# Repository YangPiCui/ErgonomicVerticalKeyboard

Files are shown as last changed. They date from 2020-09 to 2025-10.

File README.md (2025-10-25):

# Ergonomic Computer Keyboard (ECK)

## switching to FreeCAD and (extremely) slowly working on the next iteration
## let me know if you want to draw the case

## Introduction
Do you get a sore neck and stiff fingers from typing? Have you developed a stretched forth neck and a hump back?  
The keyboard and the mouse are the culprits. They force our hands to lay flat on the desk pronated, in turn stressing our neck.  
Now put your hands on the desk but rotate your palms to face each other. Do you start to feel your shoulders relaxed, your neck relieved, and your back straightened?    
The Ergonomic Computer Keyboard (ECK) allows you to feel exactly like that with the following features.
- The case orientates the key caps into a tilted formation, so that palms face each other more while typing. [[SafeType](https://safetype.com/index.php?id_product=1&controller=product) | [ergodox ez vertical stand](https://www.thingiverse.com/thing:2748084)&nbsp;| [Ergodox EZ tent kit](https://www.thingiverse.com/thing:1433117) | [A Similiar Project](https://thomasbaart.nl/2019/01/20/vertikeeb-making-a-vertical-keyboard-part-1/)]
- Concave design accomodate fingers' natural paths. [[Kinesis Advantage 2](https://kinesis-ergo.com/shop/advantage2/)  | [British patent 1,016,993](https://geekhack.org/index.php?topic=63415)]  
- An efficient, customizable keymap layout to distribute load on each finger evenly according to their relative strengths.  
- Little fingers' extra columns have been reassigned to other fingers to alleviate sore pinkies.  
- Make the keyboard as compact as possible to save desk space for extra accessories such as the mouse.  

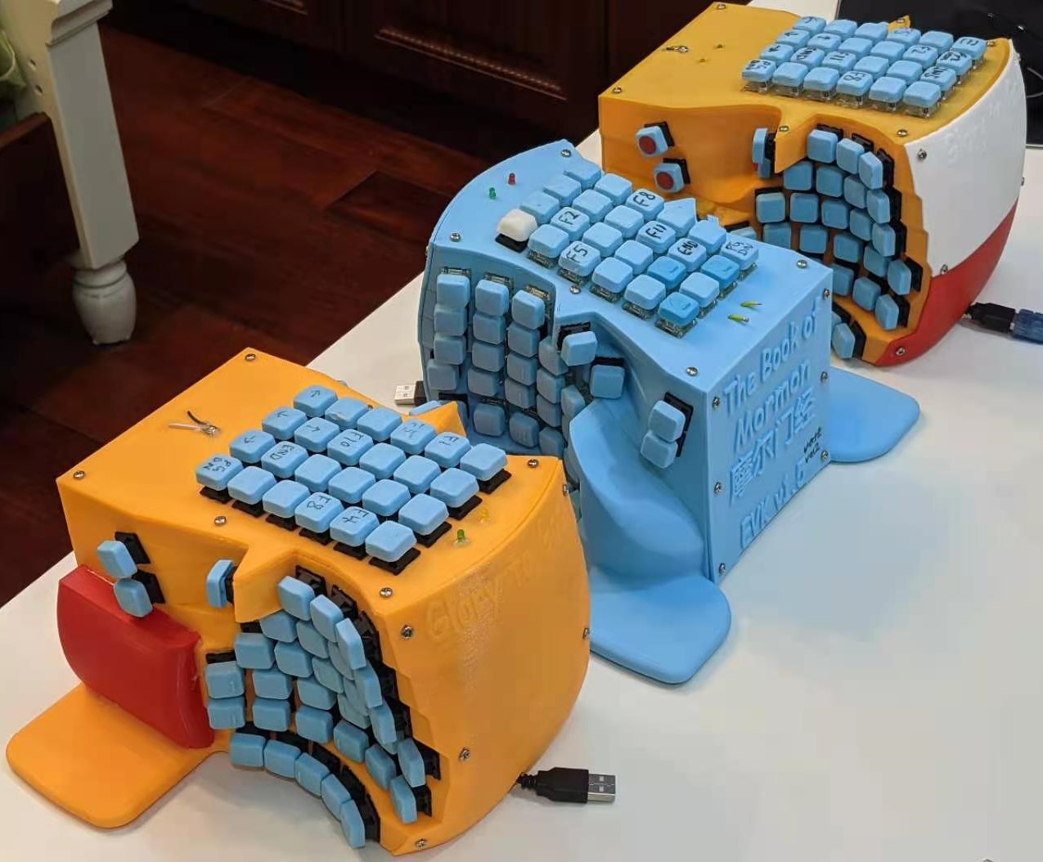
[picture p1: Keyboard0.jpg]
  
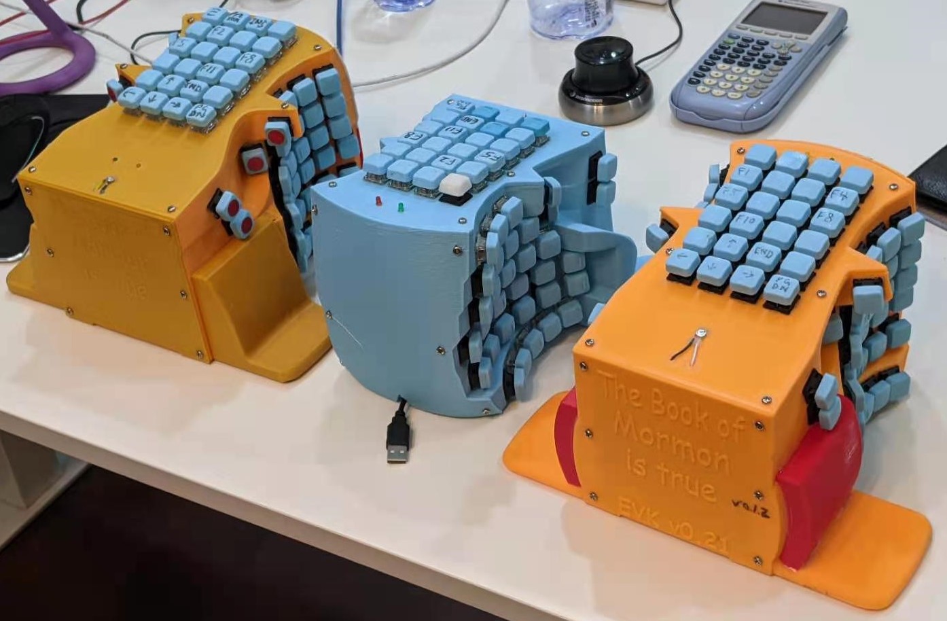
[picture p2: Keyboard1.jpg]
  

## [Versions <- click](Versions)  
I have included all necessary build instructions for each ECK version in the Versions folder.  
It takes one about one work week to build an ECK from start to finish with all the parts.

## [Keymap Optimization](KeymapOptimization) (Under Development)

## External Resources
[Main Reddit Thread](https://www.reddit.com/r/ErgoMechKeyboards/comments/g28c2i/ergonomicverticalkeyboard_thread/) | [Old](https://www.reddit.com/r/ErgoMechKeyboards/comments/fvxuw1/need_help_combining_all_of_the_good_features_from/) | [Older](https://www.reddit.com/r/MechanicalKeyboards/comments/fumlvb/possible_to_absorb_and_combine_all_of_the_good/)  

[reddit.com/r/MechanicalKeyboards/](http://reddit.com/r/MechanicalKeyboards/)&nbsp;|&nbsp;[https://www.reddit.com/r/ErgoMechKeyboards/](https://www.reddit.com/r/ErgoMechKeyboards/)  
[https://geekhack.org/](https://geekhack.org/)  
[Xah Keyboard Guide](http://Xah%20Keyboard%20Guide)  
[Reddit Post 0](https://www.reddit.com/r/MechanicalKeyboards/comments/fumlvb/possible_to_absorb_and_combine_all_of_the_good/) | [Reddit Post 1](https://www.reddit.com/r/ErgoMechKeyboards/comments/fvxuw1/need_help_combining_all_of_the_good_features_from/) | [Main Reddit Thread ](https://www.reddit.com/r/ErgoMechKeyboards/comments/g28c2i/ergonomicverticalkeyboard_thread/)  

[Ergodox](https://www.ergodox.io/)  
[Dactyl Keyboard Wiring](https://github.com/adereth/dactyl-keyboard/blob/master/guide/README.org#wiring)   
[Ergo-Dox keyboard assembly](https://www.youtube.com/watch?v=x1irVrAl3Ts)  
[Keyboard PCB Guide](https://github.com/ruiqimao/keyboard-pcb-guide)   
[GMK Carbon Original Ergodox build log](https://imgur.com/a/3riAB)  
[Dactyl Manuform Mini DIY Ergonomic Mechanical Keyboard Build Log](https://www.beekeeb.com/dactyl-manuform-mini-mechanical-keyboard-build-log/)   
[Detailed guide to making a custom keyboard](https://www.reddit.com/r/MechanicalKeyboards/comments/4l0p41/guide_detailed_guide_to_making_a_custom_keyboard/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)  
[Building your own keyboard (from scratch)](https://medium.com/@monkeytypewritr/building-your-own-keyboard-from-scratch-bd0638c40850)  

[Windows 10 Key Mapping software](https://thegeekpage.com/top-10-best-free-key-mapping-software-for-windows-10/)&nbsp;| [SharpKeys](https://github.com/randyrants/sharpkeys/releases)

## [How to Donate](https://github.com/YangPiCui/ProjectIdeas/blob/main/README.md#how-to-donate-in-descending-preference-for-me)

###### [ODC Open Database License v1.0](https://choosealicense.com/appendix/)  (free but no patent or commercial use)

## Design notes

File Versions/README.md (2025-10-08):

# Versions  
To dos:  
Rebase Github Pull Request for the firmware

## [ECK_v0.2.0](ECK_v0.2.0) (FreeCAD)
People can't blind type.
Tilt keywell instead of making it vertical.
Rename ErgonomicVerticalKeyboard to ErgonomicComputerKeyboard

## [EVK_v0.1.2](EVK_v0.1.2) (Siemens NX license expired)
I redesigned the Handrest to let hands move more freely.
* Keys
  * Chamfer the keycap stems so they don't get caught on the switches  
  * Tighten switch mount tolerance so the keys don't wiggle side to side
  * Thin the keycap walls slightly
  * Move homekey's emboss forward by 1mm.
  * keycapBaseModel stemClearance 0.02->0.03->0.04
* Key Positioning
  * finger home row resting angle p411 47->48
  * base keywell radius 87 -> 80 -> 60 ->50
  * Row separation mid 21->19->19.2; pinky 17 -> 15.3; 
  * topPlate keySpacingX keySpacingY 19.5->19->19.5->19.2
  * dZIndexToMid 19.5 -> 19 -> 19.5
  * angleIndexToMidXY 3 -> 0 -> 2 -> 3
  * knuckleRadiusXZPlane 400 -> 100 -> 170 -> 200
  * knuckleRadiusYZPlane 420 -> 500
  * Switch mount wall and other walls' thickness 1.8 -> 1.5 -> 1.65
  * Fix thin walls
  * ASM_ThumbKeys DCS1 x:40->42
  * Spacekey distance to center of rotation 50->48
  * Enter key offset -x 2->3; y 1; z 20
  * Increase LED clearance hole diameter.
  * handSeparation 220->230
  * thicknessTopPlate 2.7 -> 2.5mm
* Handrest
  * Redesign handrest to be a separate glue-on.
  * Palm Rest x 40->30->23->29->28->26->27->29, y -65 -> -40, z -20 -> -10;  angle 8->9;  
  * Bottom Rest Z -52 -> -51 -> -49 -> -50 -> -45 -> -52 -> -50 -> -49; side extension 10 -> 15; front offset 6->13->10->8
* Miscellaneous
  * Enlarge LED clearance holes
  * thicknessText .6mm

## [EVK_v0.1.1](EVK_v0.1.1)
I removed the row steps to let fingers move more freely.
* Use normal keycaps for thumbkeys
* Reduce keycap height
* Reduce keycap support area. Keycaps can now be printed without supports.
* Clean up sketch in ASM_MASTER_MidFingeColumn.prt which brings keys slightly closer to the fingers
* Use 0.4mm nozzle and 0.3mm layer height. Adjusted tolerances accordingly.
* Lower switch mount height from 2.4 to 1.8mm
* Redesign key well to replace step-like rows with a semi circle instead. This resembles Kinesis Advantage. Keycaps no longer block finger movement.
* Scale index and ring finger row separation to that of the middle finger. Apply minimum row separation for the little finger row.
* Decrease colume angles
* Flatten colume to colume curvature slightly
* Thin side walls
* Thicken top plate
* Adjust Thumbgrip to better fit the palm
* Move enter key closer to space key
* Thicken screw mounting holes  
* Front plate thicken, not extrude  
* Adjust the angle and height of the hand rests  
* Enlarge the back of the hand rests  
* Print with a better 3D printer  

## [EVK_v0.1.0](EVK_v0.1.0)
I deployed a 90 key one-piece design. This simplifies the electronics, and uses all of Teensy 2.0's pins.   
* Deploy full-sized keycaps  
* Increase row separation
* Flatten keywell slightly
* Add QWERTY keymap   
Update Versioning  
  Keyboard Layout Editor   
  Github links  
  QMK Github  

## [EVK_v0.0](EVK_v0.0) 
This is the first working prototype. It uses a split design. The firmware is based on the Dactyl Keyboard running on Teensy 2.0.

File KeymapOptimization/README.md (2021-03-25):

# Algorithmically Optimized Keymap
The layout should accommodate world's languages according to their usage.
## 0. Preparation
[The Carpalx Layout - simulated annealing](http://mkweb.bcgsc.ca/carpalx/?simulated_annealing) | [white_keyboard_layout](https://github.com/mw8/white_keyboard_layout) | [ThinQu Layout](https://microexploitation.com/2018/06/04/thinqu/)  
Download sample word data. [World's Language Usage](https://www.vistawide.com/languages/top_30_languages.htm)  
[English Letter Frequencies](https://norvig.com/mayzner.html)  
[Chinese Letter Frequencies](http://xahlee.info/kbd/chinese_pinyin_letter_frequency.html)  
Weight the frequencies with the ratio of total number of speakers of each language.  
[Top 30 languages of the world](https://www.vistawide.com/languages/top_30_languages.htm)  
Get symbol frequencies for 'spaces', 'enter', 'comma'... from literature and from codes in (C++, Python, etc.).   
[http://xahlee.info/comp/computer_language_char_distribution.html](http://xahlee.info/comp/computer_language_char_distribution.html)  

## 1. Scoring Logic
Each finger's usage should be proportional to its strength, the cube of its diameter.   
Diameter of my left index finder (LI): 56mm / LM: 54mm / LR: 53mm / LP: 47mm  
So the ratio of finger key presses should be 1.69 : 1.52 : 1.43 : 1.  
how comfortably one presses simple operations such as 'ctrl + c' needs to be taken into account.  
If a hand changes row, the other hand types two charactors.    
Change two rows with two different finger better than change two rows with the same finger.  
switch 1 or 2 rows needs the other hand to type two letters to be optimal. Switching 3 rows requires the other hand to strike 3 times.  
make the right index and mid fingers type slightly less, as most people use these two fingers to click the mouse.  

## 2. Implementation
Next step:  
1. ~~Break down the problem into smaller parts for C++.~~
2. Figure out how to do simulated annealling.

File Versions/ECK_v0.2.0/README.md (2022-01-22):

  
  
 
   
  
Please refer to EVK_v0.1.2 for build instructions.   
  
Print sideStandingMount.3mf and flatLayingMount.3mf to check switch fit and tolerance.  
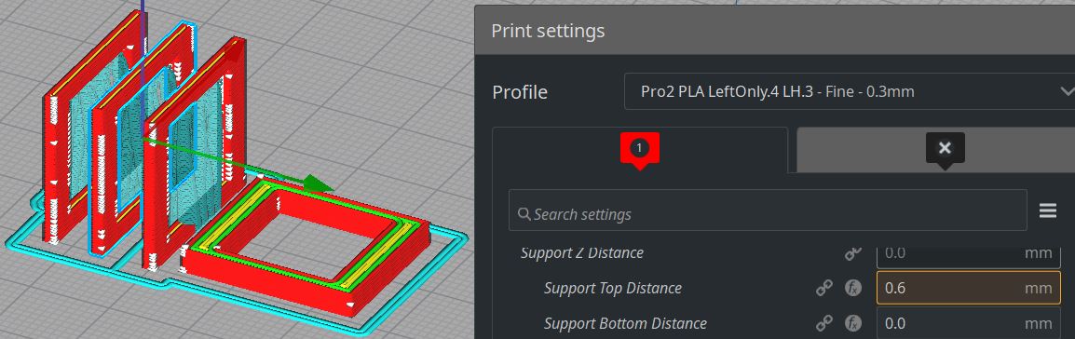
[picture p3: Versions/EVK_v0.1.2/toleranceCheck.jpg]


###### [ODC Open Database License v1.0](https://choosealicense.com/appendix/)  (free but no patent or commercial use)

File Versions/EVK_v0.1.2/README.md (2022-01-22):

  
  
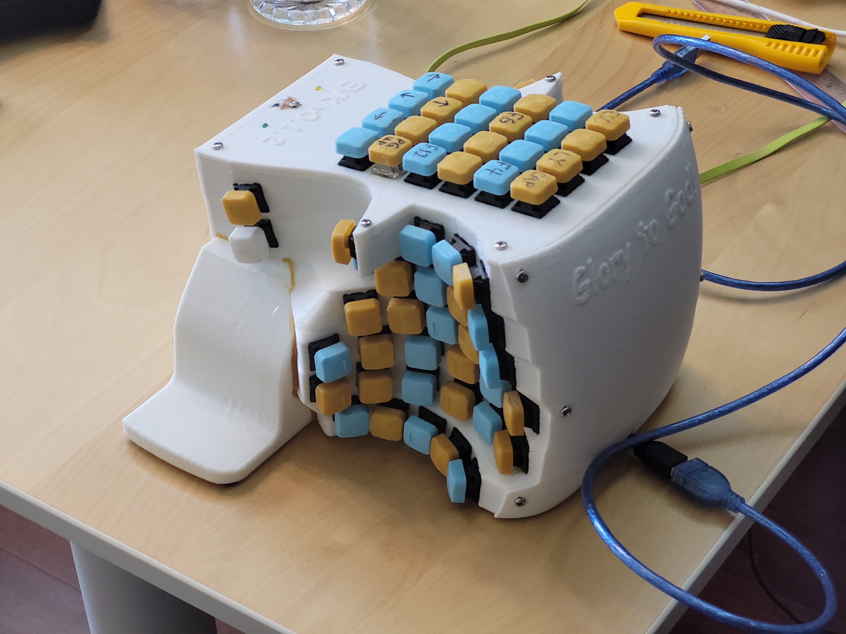
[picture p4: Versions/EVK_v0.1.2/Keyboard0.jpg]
 
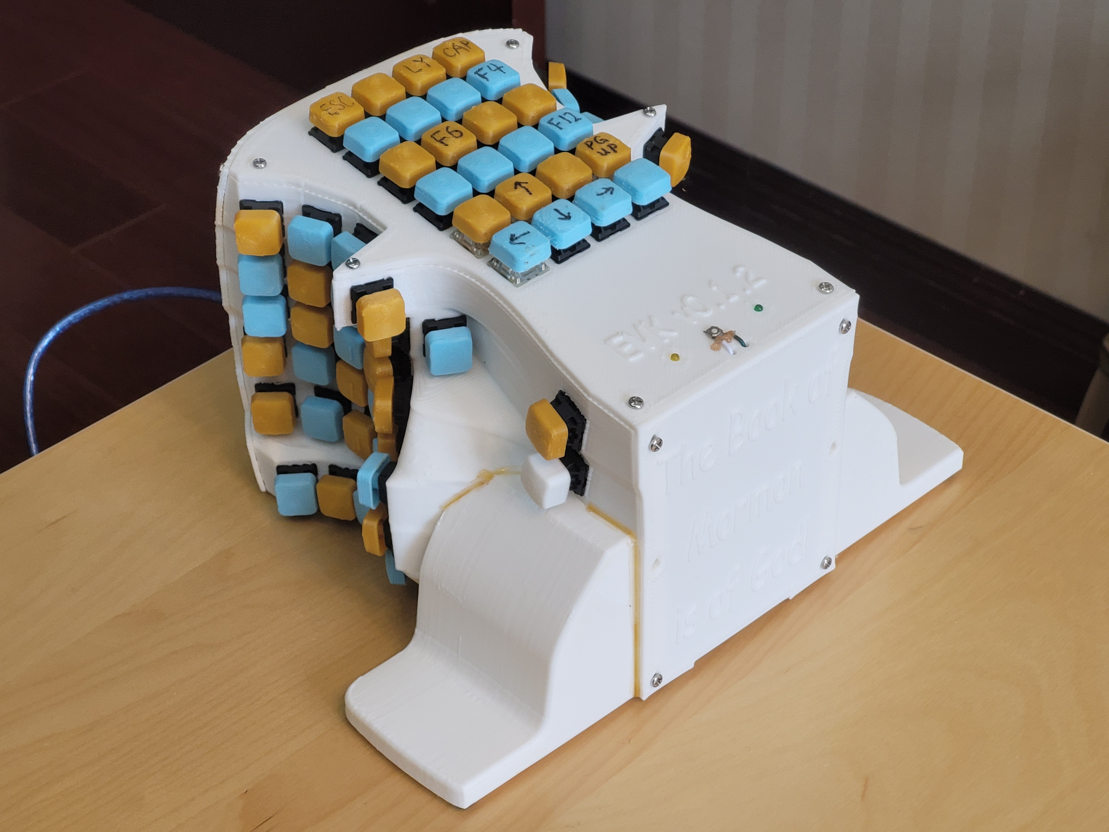
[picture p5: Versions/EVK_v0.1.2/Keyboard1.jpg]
   
  
Please refer to EVK_v0.1.1 for build instructions.   
  
Print sideStandingMount.3mf and flatLayingMount.3mf to check switch fit and tolerance.  


###### [ODC Open Database License v1.0](https://choosealicense.com/appendix/)  (free but no patent or commercial use)

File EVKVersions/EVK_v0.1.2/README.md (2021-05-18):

  
  
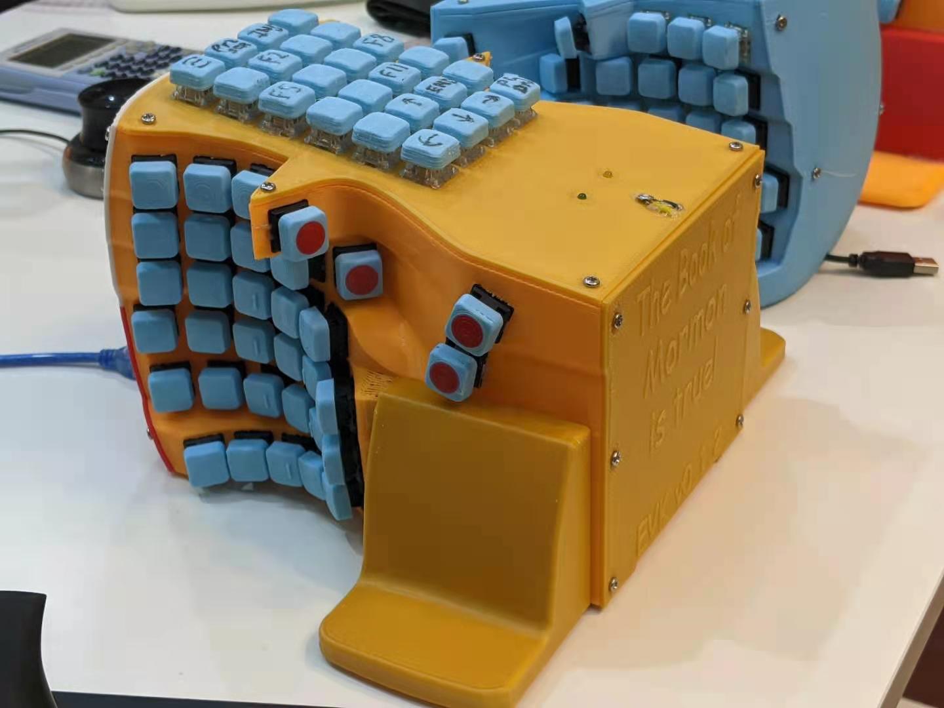
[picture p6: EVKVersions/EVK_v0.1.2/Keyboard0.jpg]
 
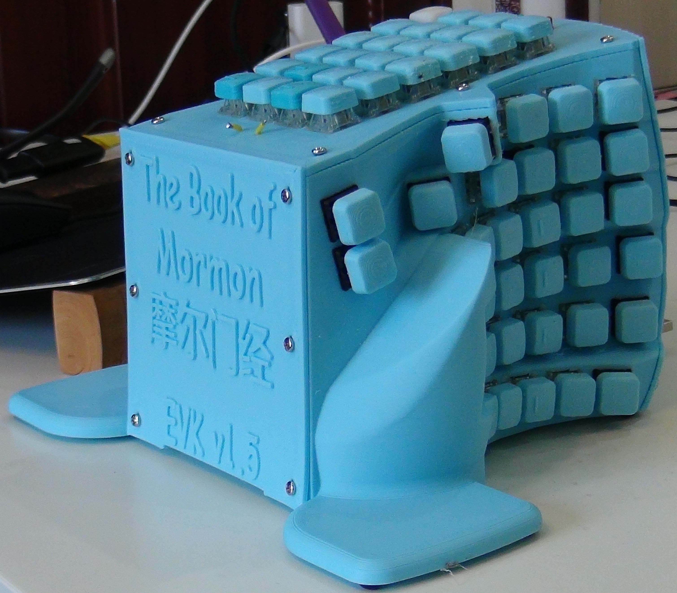
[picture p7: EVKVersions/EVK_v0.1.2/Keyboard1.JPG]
   
  
Please refer to EVK_v0.1.1  
  
Test print SwitchMountLeftRight.3mf and SwitchMountTop.3mf to check switch fit.  


###### [ODC Open Database License v1.0](https://choosealicense.com/appendix/)  (free but no patent or commercial use)

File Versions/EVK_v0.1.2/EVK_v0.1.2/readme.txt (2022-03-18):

+ ToleranceAndClearance.prt: determine the nozzle size, layer height and Support Top Distance.
+ Adjust SwitchMount.prt and test print SwitchMount3DPrintTest.prt for clearance 
    - Adjust print support top distance in Cura (2*layer height for easy support removal)
    - Adjust supportZClearance in ToleranceAndClearance.prt 
	- Adjust switch thickness. This is the side plate's wall thickness
	- Lay mount flat and remove the extra Z clearance to test the mount slots' fit on the top plate
+ ASM_Key.prt: modify the shape of keys
+ Modify master midfinger and its family parts for row separation and key orientation.
+ Case.prt
    - Adjust the curvatures in BaseKnucklePath
	- Adjust angleIndexToMidXY expression
	- Adjust dZIndexToMid expression
	- Adjust ThumbKeys positioning

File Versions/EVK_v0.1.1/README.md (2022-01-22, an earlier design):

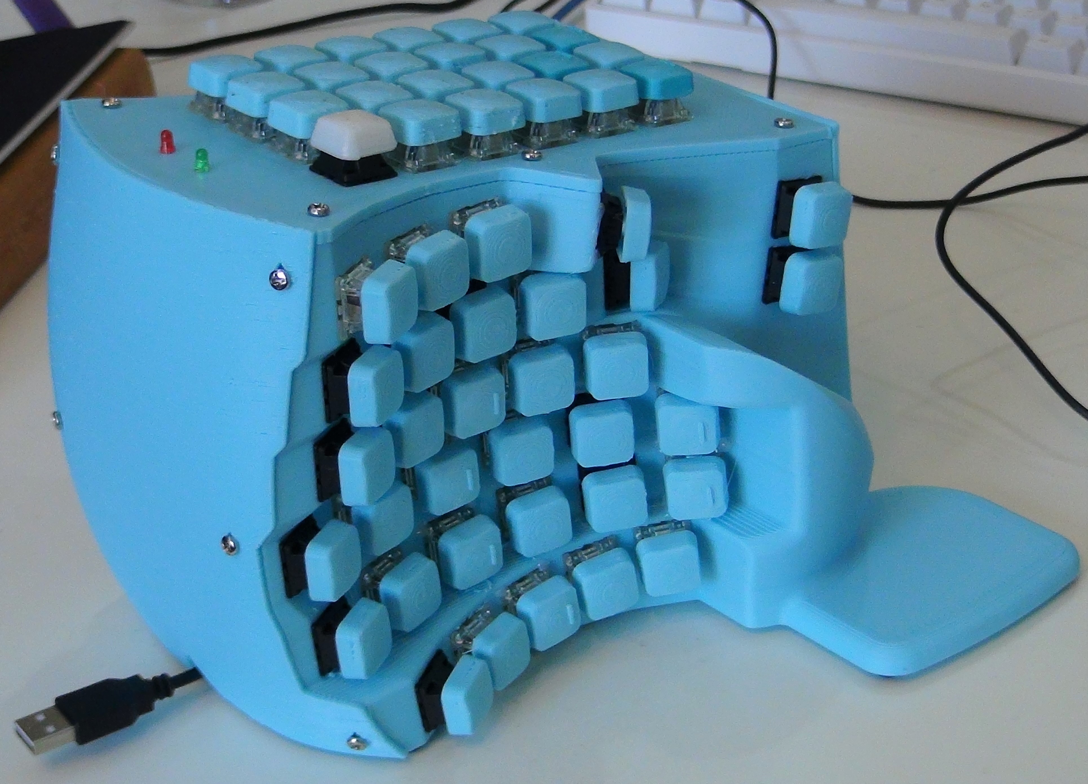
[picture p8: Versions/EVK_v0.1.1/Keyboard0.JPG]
  
  
  
Please refer to EVK_v0.1.0 for build instructions.    

### Left Right and Front  
* Nozzle Diameter 0.4mm  
* Layer Height 0.3mm  
* Line Width 0.7mm  
* Support Line Width 0.32mm  
* Tree Support Top Distance 0.6mm, or twice the layer height. IMPORTANT. Do NOT set this value greater than what I have specified, otherwise the keyswitch might not fit.  
  
### Keycaps  
* Nozzle Diameter 0.3mm  
* Layer Height = 0.15mm  

###### [ODC Open Database License v1.0](https://choosealicense.com/appendix/)  (free but no patent or commercial use)

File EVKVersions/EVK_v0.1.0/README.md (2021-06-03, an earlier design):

# 0. Part List  
* 1x Teensy 2.0 USB Board. （开发板）  
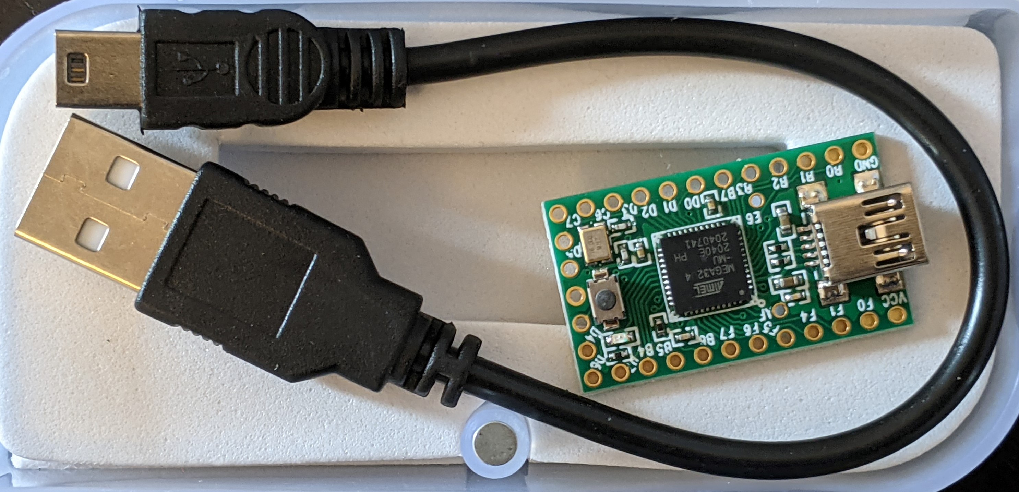
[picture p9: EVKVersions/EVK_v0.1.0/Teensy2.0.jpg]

* 90 Cherry Mechanical Switch. （樱桃轴）
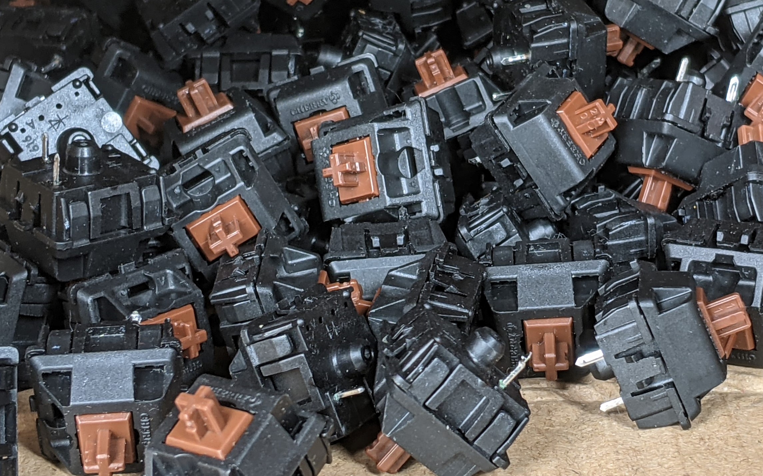
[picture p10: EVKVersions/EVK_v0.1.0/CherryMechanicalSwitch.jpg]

* 90 1N4148 diode.（开关二极管）One diode for each key switch.
* 2x 3mm T1 LEDs. （发光二极管）  
* 2x 1kΩ resistors to connect in series with the LEDs.（电阻）
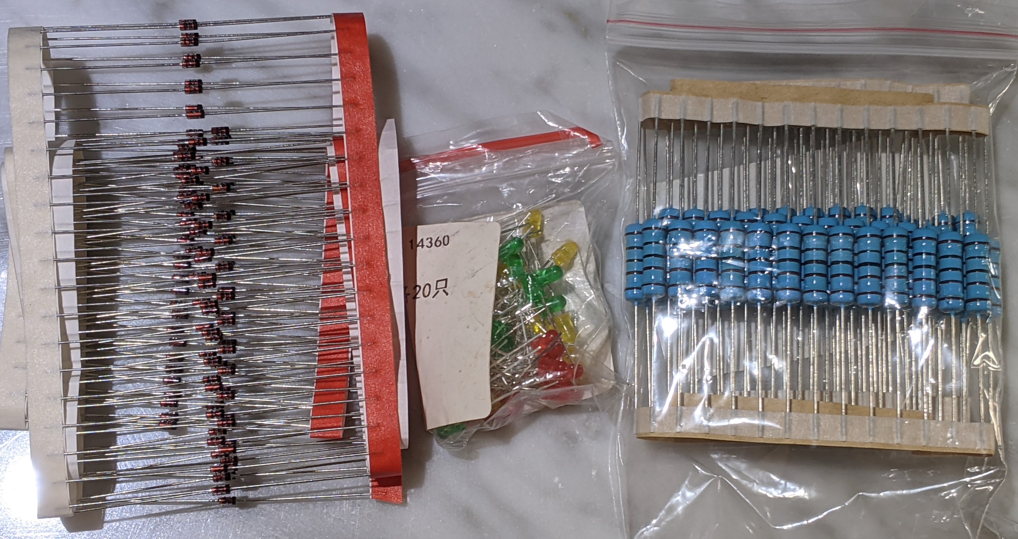
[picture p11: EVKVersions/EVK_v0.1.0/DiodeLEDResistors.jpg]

* 0.6mm (wire diameter) tin-coated naked wire.
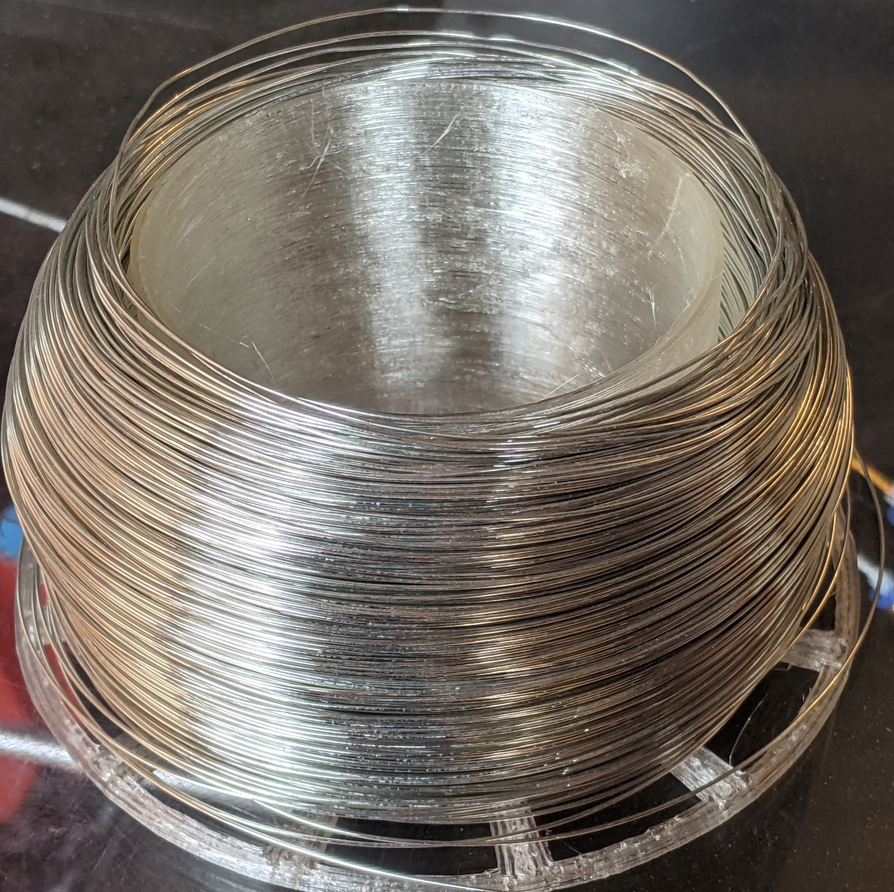
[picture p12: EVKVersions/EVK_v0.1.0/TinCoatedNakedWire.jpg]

* 20cm long, 0.6mm (core diameter) sillicon wrapped wire. Get these pre-soldered ones to save time.
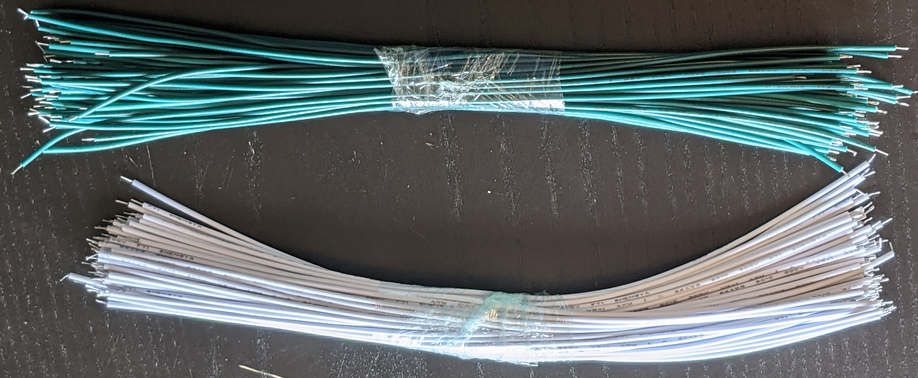
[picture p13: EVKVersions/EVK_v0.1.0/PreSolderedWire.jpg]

* 24 M3x6mm flat tip self-tap screws.
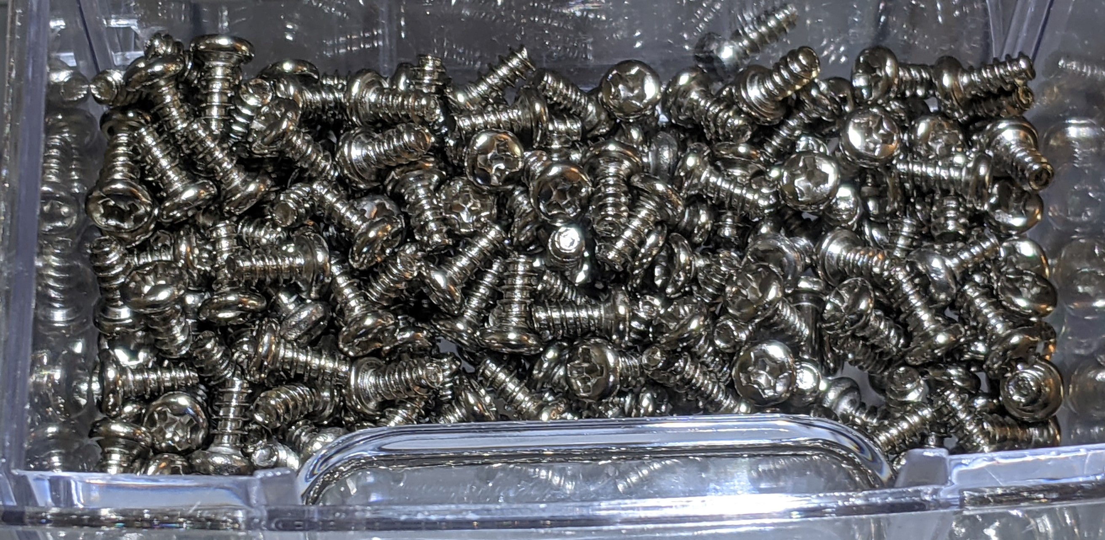
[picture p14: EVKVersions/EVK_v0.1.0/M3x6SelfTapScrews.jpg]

* 10 8mm diameter x 3mm tall silicon dome sticker feet.
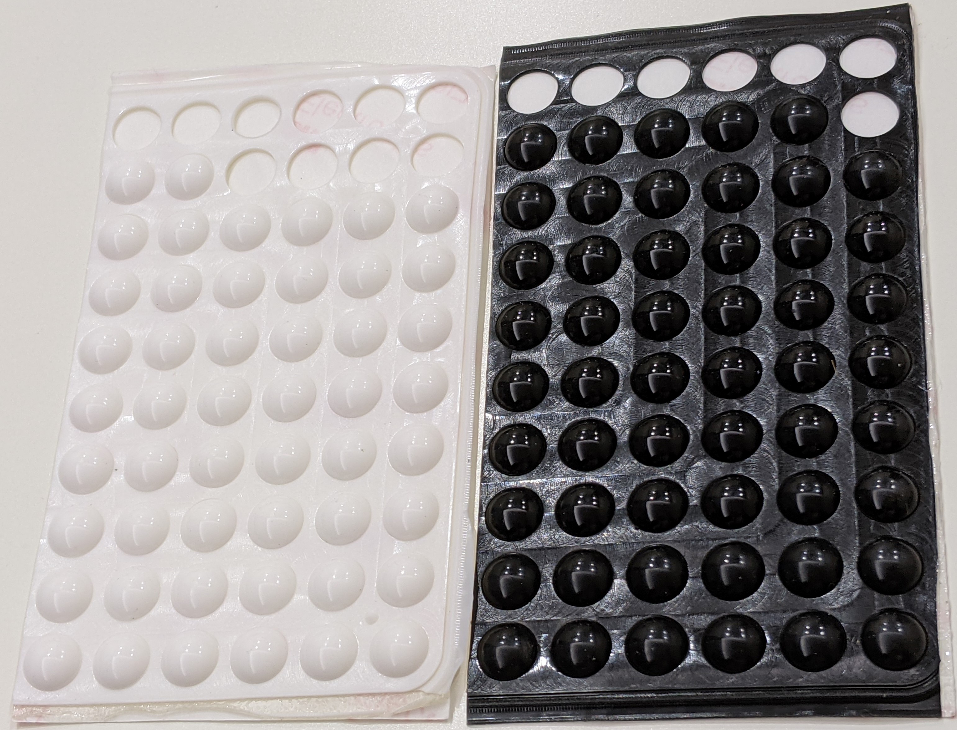
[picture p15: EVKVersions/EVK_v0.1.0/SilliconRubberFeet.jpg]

* Soldering Iron and Hot Glue Gun.

# [1. Case Design](CaseDesign) 
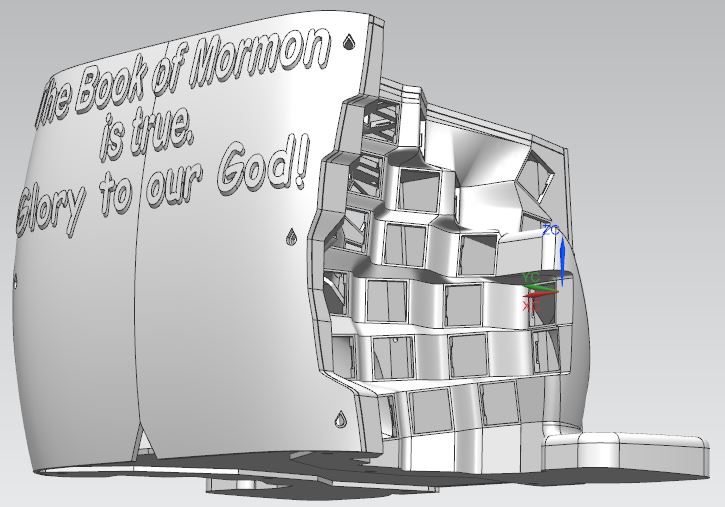
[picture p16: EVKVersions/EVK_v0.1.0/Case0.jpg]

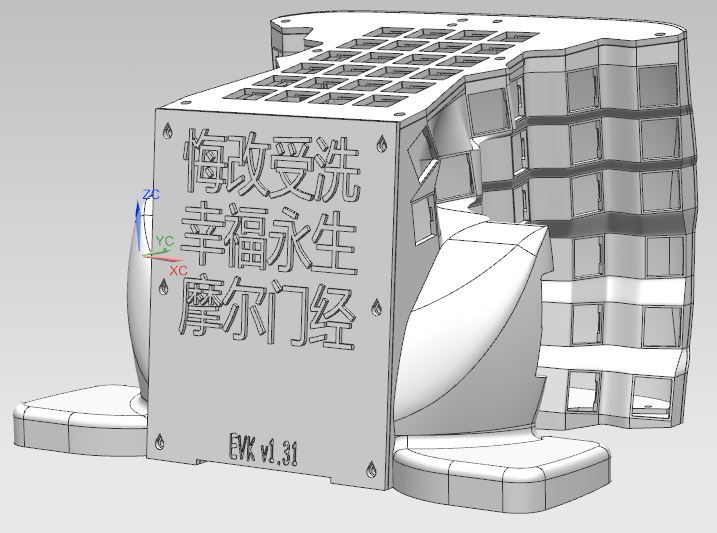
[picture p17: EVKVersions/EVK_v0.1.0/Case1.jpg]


# 2. Keymap 
[Layer0](http://www.keyboard-layout-editor.com/#/gists/2fc38dca845ec5f253bac7c052df82da)  
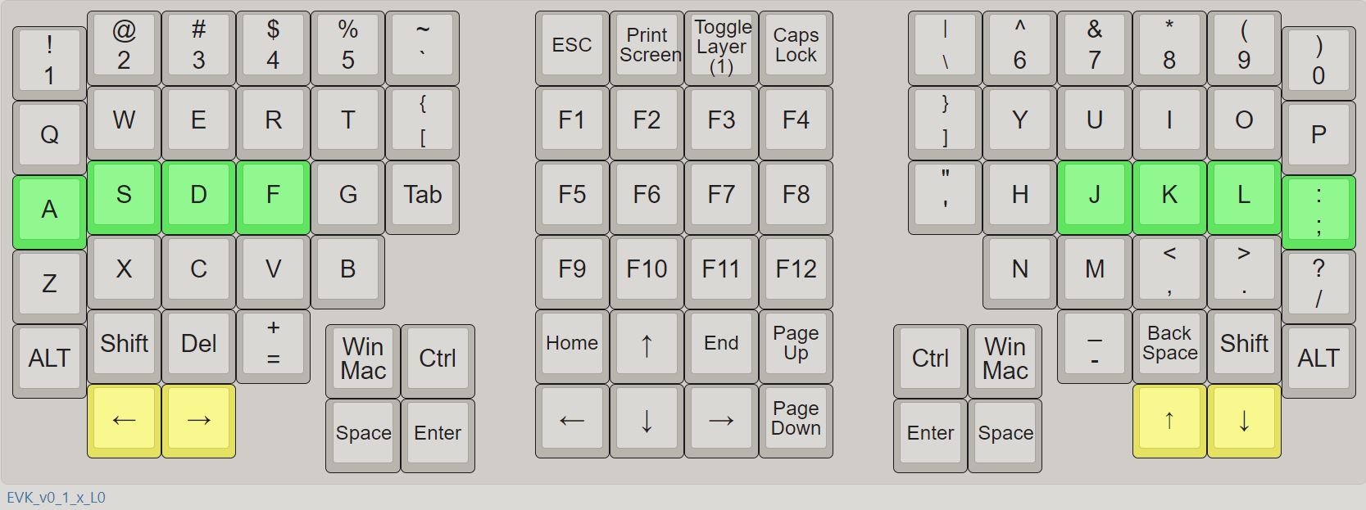
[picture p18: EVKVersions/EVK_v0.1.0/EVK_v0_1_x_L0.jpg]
  
[Layer1](http://www.keyboard-layout-editor.com/#/gists/1d35c2bdc8fc2de6860daa4e2ee97f45)  
I manually designed a keymap based on English [letter](https://norvig.com/mayzner.html) and [character](http://xahlee.info/comp/computer_language_char_distribution.html) frequencies. [It fares well against other traidtional layouts according to the Keyboard Layout Analyzer.](http://patorjk.com/keyboard-layout-analyzer/#/load/hqrGn4NG)  
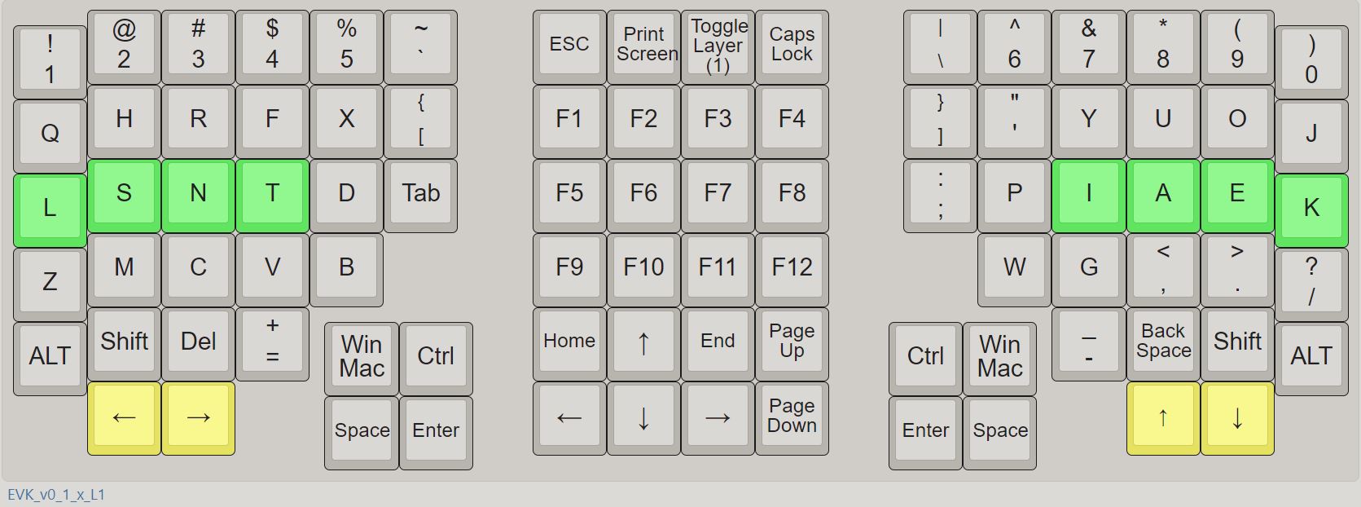
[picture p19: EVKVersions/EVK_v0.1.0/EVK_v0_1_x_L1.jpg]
  

# [3. Electronics, Firmware and Software](ElectronicsFirmwareAndSoftware)

# 4. 3D Print 
"./3DPrintFiles/"  
"./CuraSlicerSettings/" 
The parts are of high precision. The fits are transitional clearance. [Calibrate](https://github.com/YangPiCui/3DPrinterCalibrationAndTuning/) your 3D printer accurately and follow the instructions closely. 

### Left Right and Front  
* Nozzle Diameter 0.3mm
* Layer Height 0.24mm
* Line Width 0.54mm
* Support Line Width 0.24mm for easy support removal   
* Tree Support Top Distance is 0.48mm, or twice the layer height. IMPORTANT. Do NOT set this value greater than what I have specified, otherwise the keyswitch might not fit. 
Print the Left Right and Front as if they would normally stand on the build plate. Set brim distance to 0mm for Front but not for Left or Right.  
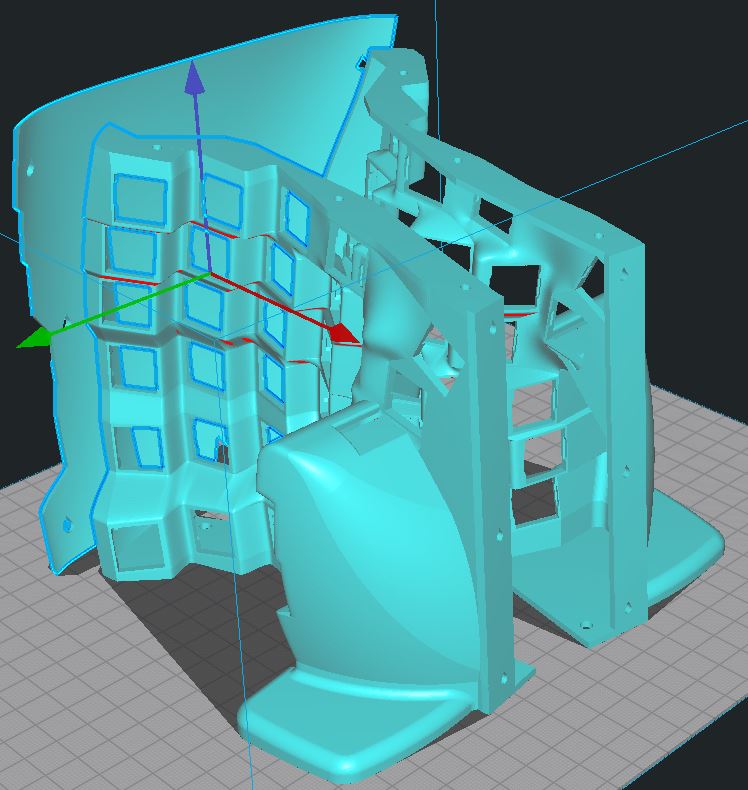
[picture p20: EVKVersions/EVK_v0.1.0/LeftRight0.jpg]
  
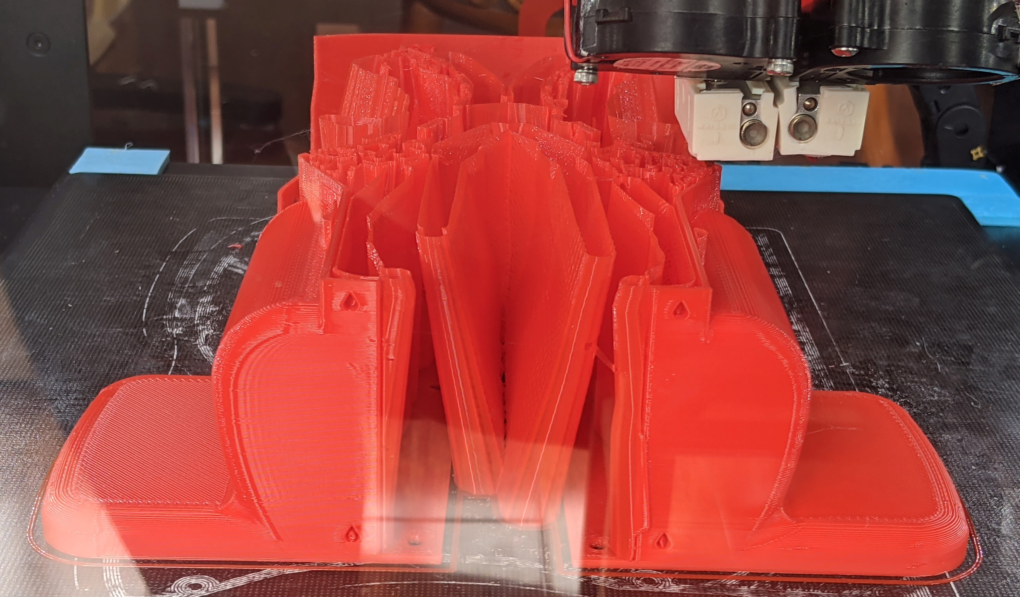
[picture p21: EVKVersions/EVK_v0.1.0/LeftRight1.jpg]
  
  
### Top Bottom and Back
If switches do not fit on the Top Plate. Try adjusting the Horizontal Expansion in Cura. 
  
### Keycaps
The keycaps are a press-fit onto the Cherry Switches!  
* Nozzle Diameter 0.3mm
* Layer Height = 0.16mm 
* Support still needed in this version. No support necessary starting at v0.1.1. 
* Brim & Support Brim = off; They are painful to remove.  
Print the keycaps as if they would sit on the build plate.  
KeycapHome x 12 (8 for the home row and 4 for the most bottom row)   
KeycapThumb x 4   
KeycapNormal x 74   
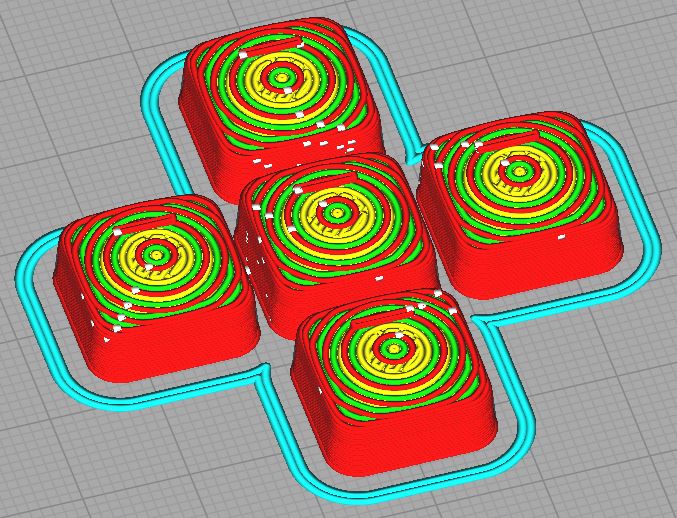
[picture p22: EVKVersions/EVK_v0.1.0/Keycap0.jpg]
    
Use a knife to trim the excess edges of the printed keycaps.

## 5. Assembly

### Hot-glue Cherry Key Switches
Put some hot glue on the four corners of each keyswitch to secure it on the plates. Do it on the inside for a nicer outer finish.
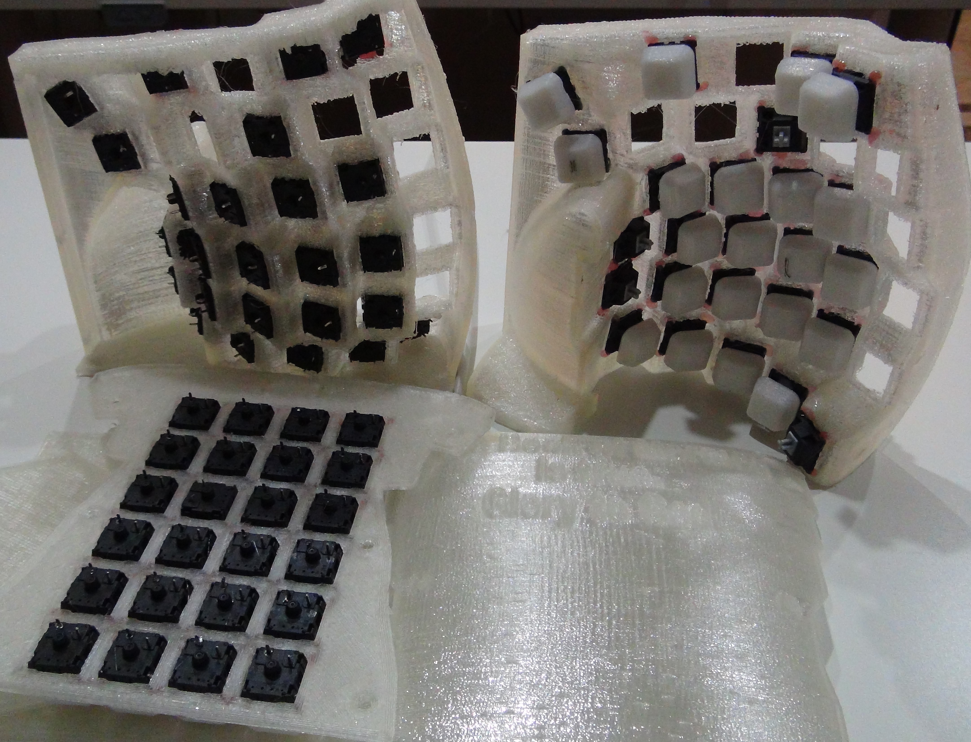
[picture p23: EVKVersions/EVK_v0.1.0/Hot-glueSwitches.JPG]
  

### Wire up the Keyboard Matrix  
Rows and columns on the physical keyboard:  
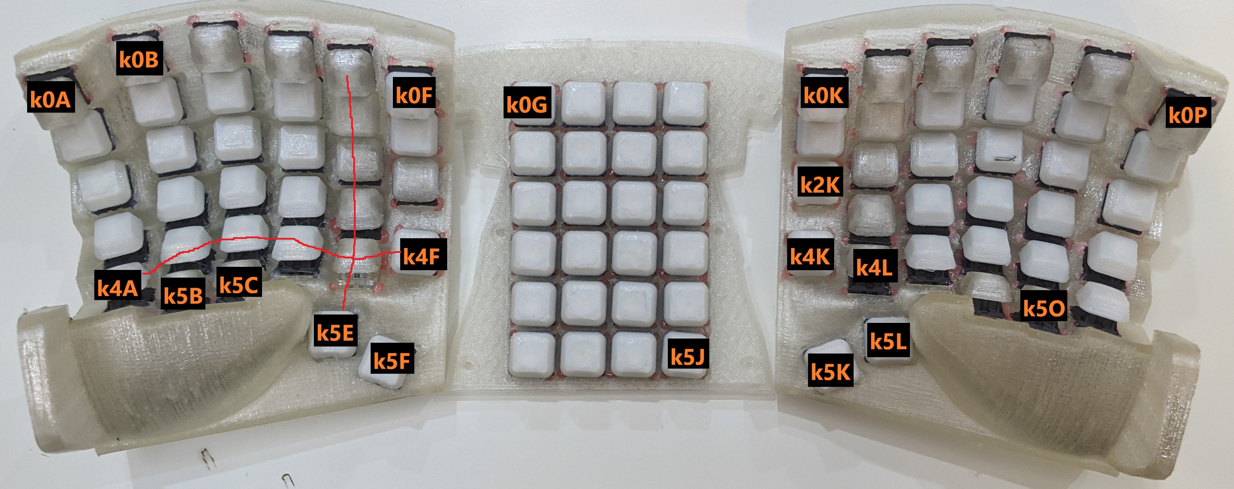
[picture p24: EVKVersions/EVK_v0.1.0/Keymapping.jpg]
  
Note #define DIODE_DIRECTION ROW2COL in config.h -- current flows from the positive Teensy pins into the matrix rows and out of the columns to the ground pin.  

### 0. Rows  
I used a naked wire to connect the switches on each row together. 
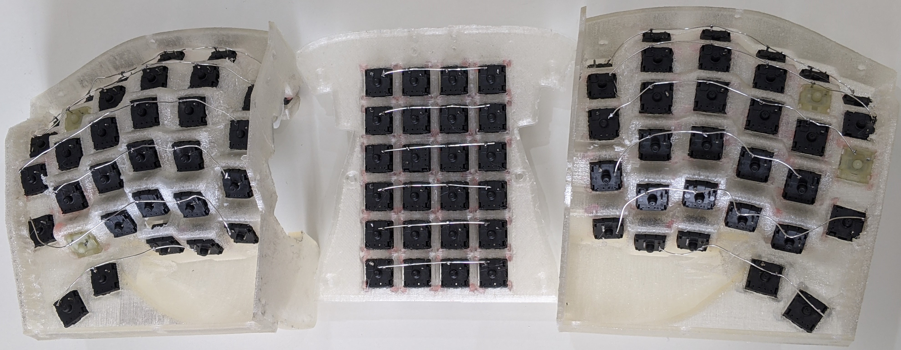
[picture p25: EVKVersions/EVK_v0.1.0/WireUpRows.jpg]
 

### 1. Columns
First solder the diodes. The diodes need the black bar facing away from the key. The diode's black bar indicates its negative terminal.  
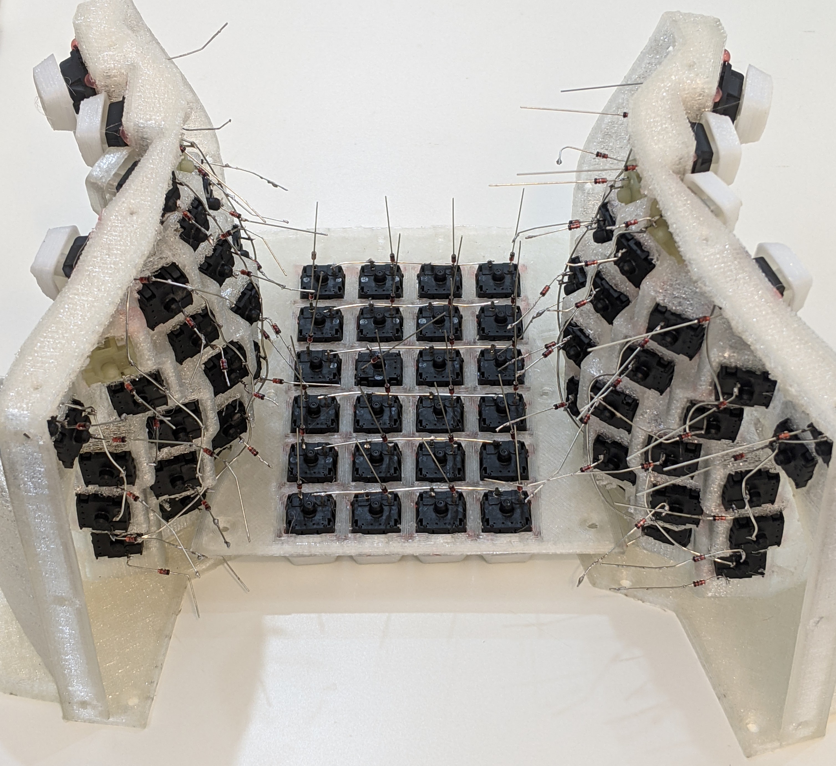
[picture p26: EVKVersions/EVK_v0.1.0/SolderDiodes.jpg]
  
  
Wire up the columns.  
  
  
Connect the rows.  
  

### Wire up the Micro Controller
Refer to the [3. Electronics, Firmware and Software](ElectronicsFirmwareAndSoftware) section for Teensy pinouts.
Capslock LED on pin D4 and layer switch indictation on pin D5.    
  
  
LEDsAndResetButton  
  

### Put on the Sillicon Rubber Feet  
  

### Smile



###### [ODC Open Database License v1.0](https://choosealicense.com/appendix/)  (free but no patent or commercial use)

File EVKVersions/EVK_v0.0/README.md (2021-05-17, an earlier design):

# [Case](Case) 

# [Keymap Optimization](KeymapOptimization) 

# [Electronics, Firmware and Software](ElectronicsFirmwareAndSoftware)
EVK v0.0 uses the Teensy 2.0 micro-controller and 72 Cherry Mechanical Switches.




###### [ODC Open Database License v1.0](https://choosealicense.com/appendix/)  (free but no patent or commercial use)

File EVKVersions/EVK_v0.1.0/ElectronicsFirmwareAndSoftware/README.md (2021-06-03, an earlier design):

# Electronics Firmware And Software

## 0. Compile the Firmware in the QMK Configurator 
Open the [QMK Configurator](https://config.qmk.fm/#/handwired/evk/v1_3/LAYOUT), follow the [QMK Configurator Guide](https://docs.qmk.fm/#/newbs_building_firmware_configurator), load /handwired/evk/v0_1_x, modify the keymap to your liking, compile, and generate the .hex file.  
Default keymaps for the Configurator are added here: https://github.com/qmk/qmk_configurator/tree/master/public/keymaps  
It does not use the default keymap.c from the qmk_firmware repo.  

## 1.0 [Alternatively] Code the QMK Firmware for EVK from scratch
Install [QMK MSYS](https://beta.docs.qmk.fm/tutorial/newbs_getting_started)  
[Or install MSYS2 manually](https://docs.qmk.fm/#/newbs_getting_started)  
* During Windows setup, follow [this](https://stackoverflow.com/questions/41932407/which-python-should-i-install-and-how-when-using-msys2) and [this](https://stackoverflow.com/questions/48087004/installing-pip-on-msys) to install Python3 and pip on MSYS2.  
* Open up C:\MSYS64\home\(username)\qmk_utils\activate_msys2.sh, and add cd ~/qmk_firmware, or whatever the path is. That way, when you open up MSYS, it will automatically start in the qmk directory.

### 1.1 Fork https://github.com/qmk/qmk_firmware on Github
[Step-by-step guide to contributing on GitHub](https://www.dataschool.io/how-to-contribute-on-github/)  
[Keep the forked repository and the local copy up-to-date](https://www.earthdatascience.org/courses/intro-to-earth-data-science/git-github/github-collaboration/update-github-repositories-with-changes-by-others/)   
Local QMK Repository Path: C:\Users\<UserName>\qmk_firmware  

### 1.2 Write Custom Codes
[Understand the keyboard matrix](https://www.dribin.org/dave/keyboard/one_html/)   
[Rollover, blocking and ghosting](https://deskthority.net/wiki/Rollover,_blocking_and_ghosting)   
[Understanding QMK’s Code](https://docs.qmk.fm/#/understanding_qmk?id=matrix-to-physical-layout-map)   
  
Copy /keyboards/handwired/dactyl_left into /keyboards/handwired/evk and modify the files according to [these guidelines](https://docs.qmk.fm/#/hardware_keyboard_guidelines?id=custom-keyboard-programming).  
  
#### 1.2.0 "/handwired/evk/"
* readme.md - update   
* info.json - update 

#### 1.2.1 "/handwired/evk/v0_1_x/"    
* readme.md - update   
* rules.mk - no change  
* config.h  
  * change matrix size to 6(rows) x 16(cols) 
  * define the matrix row and col pins for the [Teensy 2.0](https://www.pjrc.com/teensy/pinout.html)
  * #define DIODE_DIRECTION ROW2COL // the current flows into the rows and then out of the columns  
  * [define status LEDs](https://docs.qmk.fm/#/feature_led_indicators?id=configuration-options)
```c
#define MATRIX_ROWS 6
#define MATRIX_COLS 16
#define MATRIX_ROW_PINS \
    { B0, B1, B2, B3, B7, D0 }  // row 0, 1, 2, ...
#define MATRIX_COL_PINS \
    { D1, D2, D3, C6, C7, F0, F1, F4, F5, F6, F7, B6, B5, B4, D7, D6 }  // column 0, 1, 2, 3, ...
#define DIODE_DIRECTION ROW2COL
#define LED_CAPS_LOCK_PIN D4  //This same pin is used in v1_3.c to switch the LED on/off
```  
Teensy 2.0 Pinout in C Language

* v0_1_x.c
  * Add the codes to control status LEDs ([Layer Change Code](https://docs.qmk.fm/#/custom_quantum_functions?id=layer-change-code))
```c
void matrix_init_kb(void) {
    // Set the LEDs pins
    setPinOutput(D5); // Layer 1 Status LED

    matrix_init_user();
}

__attribute__((weak)) layer_state_t layer_state_set_user(layer_state_t state) {
    writePin(D5, layer_state_cmd(state, 1));
    return state;
}

bool led_update_kb(led_t led_state) {
    bool res = led_update_user(led_state);
    if (res) {
        // writePin sets the pin high for 1 and low for 0.
        writePin(D4, led_state.caps_lock);
    }
    return res;
}
```

* v0_1_x.h    
  * map the matrix to physical layout ([How the Configurator Understands Keyboards](https://docs.qmk.fm/#/reference_configurator_support?id=how-the-configurator-understands-keyboards) | [the keymap variables can be whatever as long as they are unique](https://www.reddit.com/r/olkb/comments/42ohxz/crazy_columns_and_tons_of_keys_with_qmk/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))
```c
#define LAYOUT(\
      k0A, k0B, k0C, k0D, k0E, k0F,    k0G, k0H, k0I, k0J,    k0K, k0L, k0M, k0N, k0O, k0P, \
      k1A, k1B, k1C, k1D, k1E, k1F,    k1G, k1H, k1I, k1J,    k1K, k1L, k1M, k1N, k1O, k1P, \
      k2A, k2B, k2C, k2D, k2E, k2F,    k2G, k2H, k2I, k2J,    k2K, k2L, k2M, k2N, k2O, k2P, \
      k3A, k3B, k3C, k3D, k3E,         k3G, k3H, k3I, k3J,         k3L, k3M, k3N, k3O, k3P, \
      k4A, k4B, k4C, k4D, k4E,  k4F,   k4G, k4H, k4I, k4J,   k4K,  k4L, k4M, k4N, k4O, k4P, \
           k5B, k5C,       k5E, k5F,   k5G, k5H, k5I, k5J,   k5k, k5L,       k5N, k5O       \
) { \
    { k0A, k0B, k0C, k0D, k0E, k0F,    k0G, k0H, k0I, k0J,    k0K, k0L, k0M, k0N, k0O, k0P }, \
    { k1A, k1B, k1C, k1D, k1E, k1F,    k1G, k1H, k1I, k1J,    k1K, k1L, k1M, k1N, k1O, k1P }, \
    { k2A, k2B, k2C, k2D, k2E, k2F,    k2G, k2H, k2I, k2J,    k2K, k2L, k2M, k2N, k2O, k2P }, \
    { k3A, k3B, k3C, k3D, k3E,  XXX,   k3G, k3H, k3I, k3J,   XXX,  k3L, k3M, k3N, k3O, k3P }, \
    { k4A, k4B, k4C, k4D, k4E,  k4F,   k4G, k4H, k4I, k4J,   k4K,  k4L, k4M, k4N, k4O, k4P }, \
    { XXX, k5B, k5C, XXX,  k5E, k5F,   k5G, k5H, k5I, k5J,   k5k, k5L,  XXX, k5N, k5O, XXX }  \
}
```

* info.json ([Supporting Your Keyboard in QMK Configurator](https://docs.qmk.fm/#/reference_configurator_support))
  * build the [keymap](../Keymap) in the Keyboard Layout Editor
  * convert its raw data into .json format with the [QMK KLE-JSON Converter](https://qmk.fm/converter/) 
  * override the existing contents of info.json with the converted contents 
  * in [QMK Configurator](https://config.qmk.fm/), press Ctrl+Shift+I to upload the new info.json file and check if it's correct.
```
{
    "width": 22.75,
    "height": 7.5,
    "layouts": {
        "LAYOUT": {
            "layout": [
                {"label":"k0A", "x":0, "y":0.5, "w":1.25, "h":1.25},
                {"label":"k0B", "x":1.25, "y":0.25, "w":1.25, "h":1.25},
                {"label":"k0C", "x":2.5, "y":0, "w":1.25, "h":1.25},
                ...
                {"label":"k5N", "x":19, "y":6.25, "w":1.25, "h":1.25},
                {"label":"k5O", "x":20.25, "y":6.5, "w":1.25, "h":1.25}
            ]
        }
    }
}
```

#### 1.2.2 "/handwired/evk/v0_1_x/keymaps/default"
* readme.md - update
* keymap.c 
  * look up the [default keycodes](https://docs.qmk.fm/#/faq_keymap?id=what-are-the-default-keycodes) and [customize The Layout To Your Liking](https://docs.qmk.fm/#/newbs_building_firmware?id=customize-the-layout-to-your-liking).  

### 1.3 Compile the Firmware 
In MSYS2, type
```c
qmk compile -kb handwired/evk/v0_1_x -km default
```
The generated .hex file is located at /qmk_firmware/.build/ on the local computer.  
I have included a copy of the .hex file in the current GitHub folder.     
If giving "Error: C:/Users/<UserName>/qmk_firmware is too old or not set up correctly!", run ["python3 -m pip install pygments"](https://github.com/qmk/qmk_firmware/issues/10602) and ["python3 -m pip install -U qmk"](https://github.com/qmk/qmk_firmware/issues/10602) in MSYS2.  

## 2. Flash Firmware Onto the Micro-controller
Use the [Teensy Loader](https://www.pjrc.com/teensy/loader_win10.html) to flash the .hex file onto the Teensy 2.0 microcontroller.

###### [ODC Open Database License v1.0](https://choosealicense.com/appendix/)  (free but no patent or commercial use)

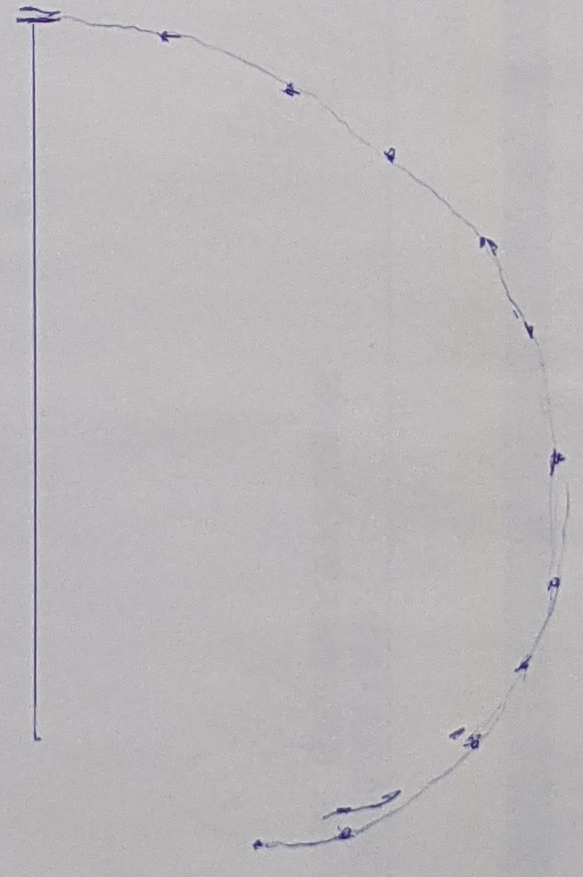
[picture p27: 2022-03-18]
Versions/EVK_v0.1.2/EVK_v0.1.2/MidFingerPath.jpg

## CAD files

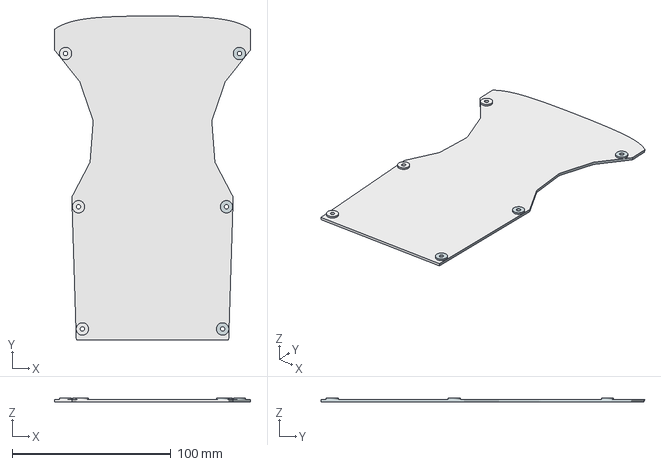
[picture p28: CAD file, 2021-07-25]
EVKVersions/EVK_v0.1.2/3DPrinterFiles/Bottom.3mf
123.4 x 203.9 x 2.75 mm

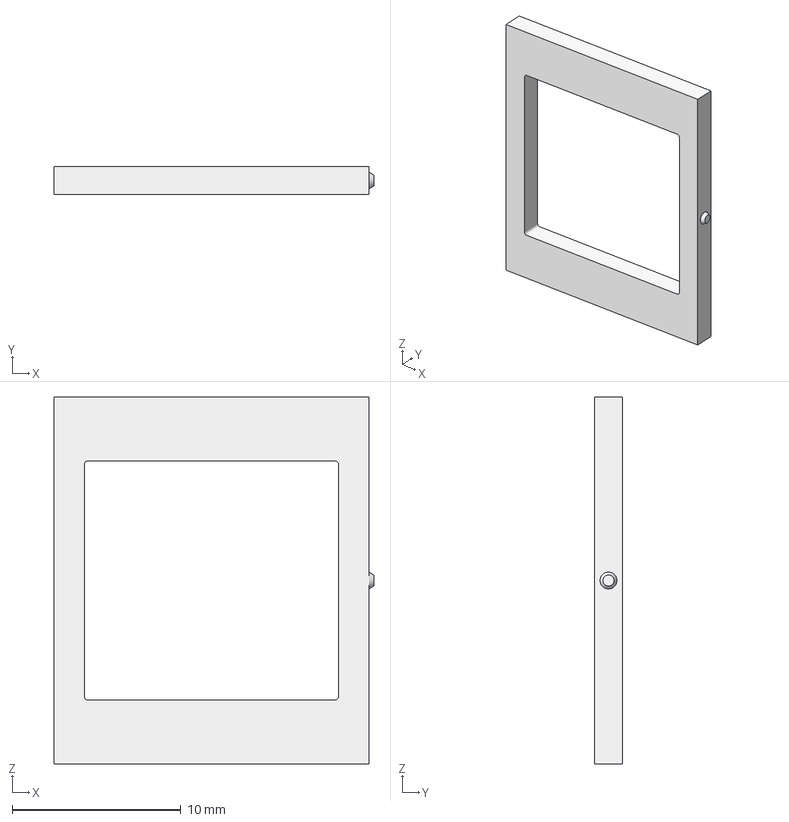
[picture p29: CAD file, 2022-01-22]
Versions/EVK_v0.1.2/3DPrinterFiles/sideStandingMount.3mf
19.0 x 1.65 x 21.8 mm

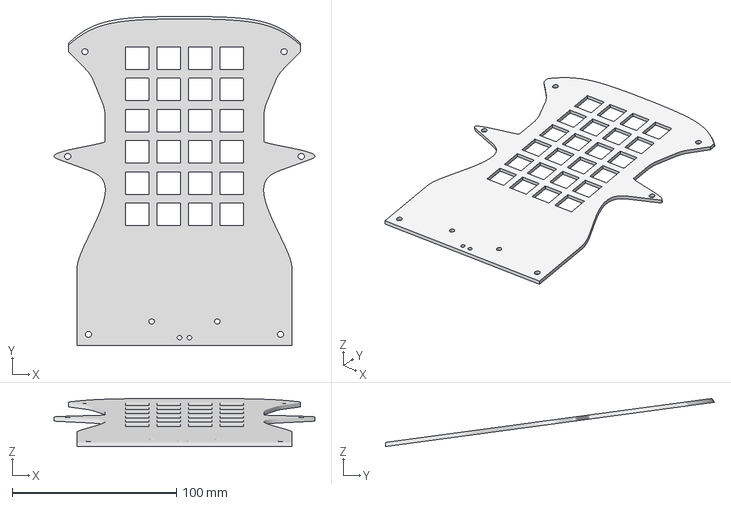
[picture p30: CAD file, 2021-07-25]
EVKVersions/EVK_v0.1.2/3DPrinterFiles/Top.3mf
158.9 x 200.6 x 29.3 mm

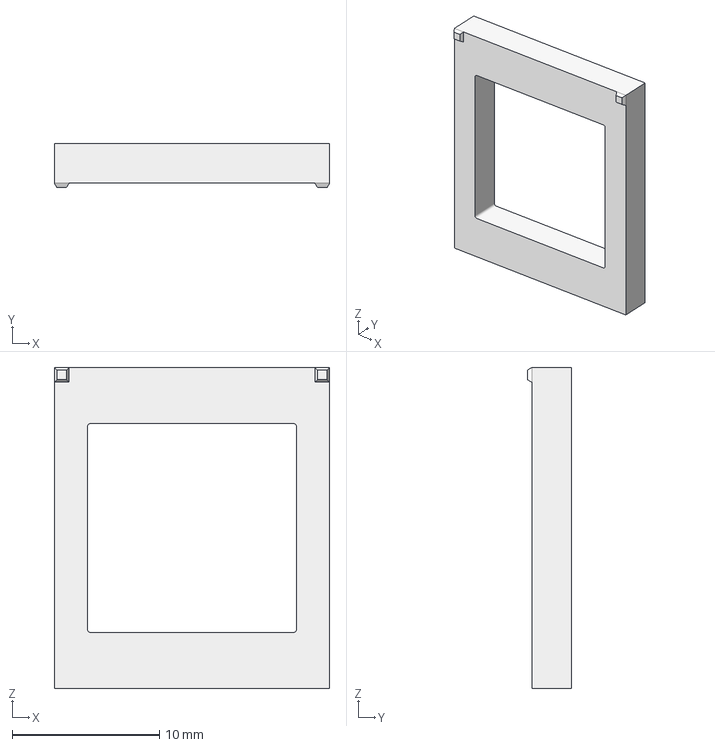
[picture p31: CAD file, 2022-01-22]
Versions/EVK_v0.1.2/3DPrinterFiles/flatLayingMount.3mf
18.7 x 3.00 x 21.8 mm

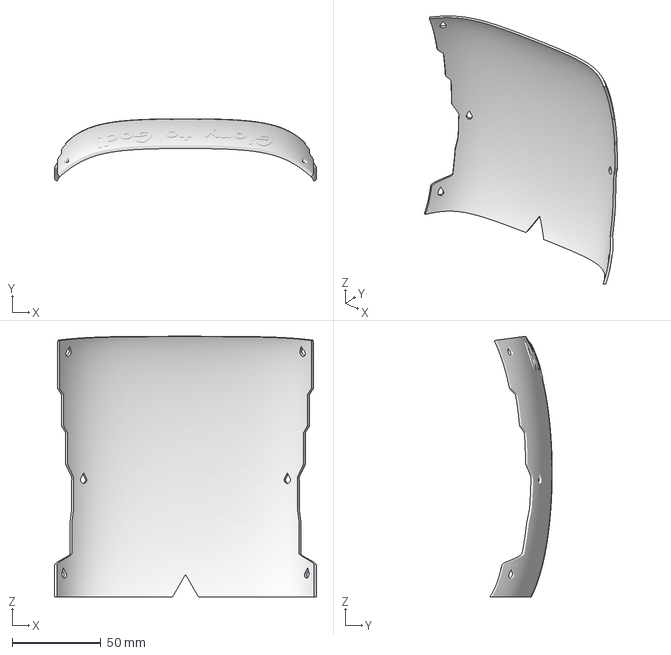
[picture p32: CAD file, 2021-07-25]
EVKVersions/EVK_v0.1.2/3DPrinterFiles/Front.3mf
147.5 x 35.2 x 146.6 mm

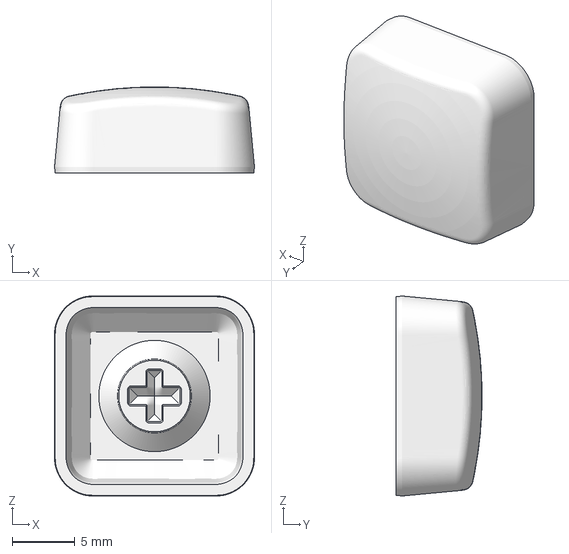
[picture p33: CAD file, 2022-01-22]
Versions/EVK_v0.1.2/3DPrinterFiles/KeyCapNormal.3mf
15.9 x 6.87 x 15.9 mm

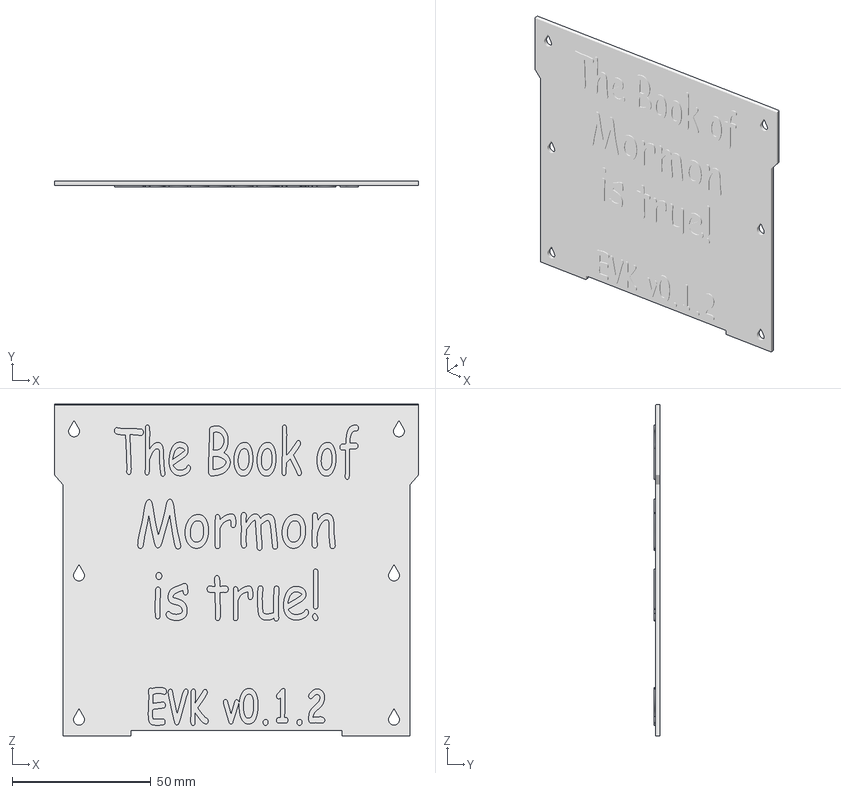
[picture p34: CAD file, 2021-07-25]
EVKVersions/EVK_v0.1.2/3DPrinterFiles/Back.3mf
131.2 x 2.25 x 119.5 mm

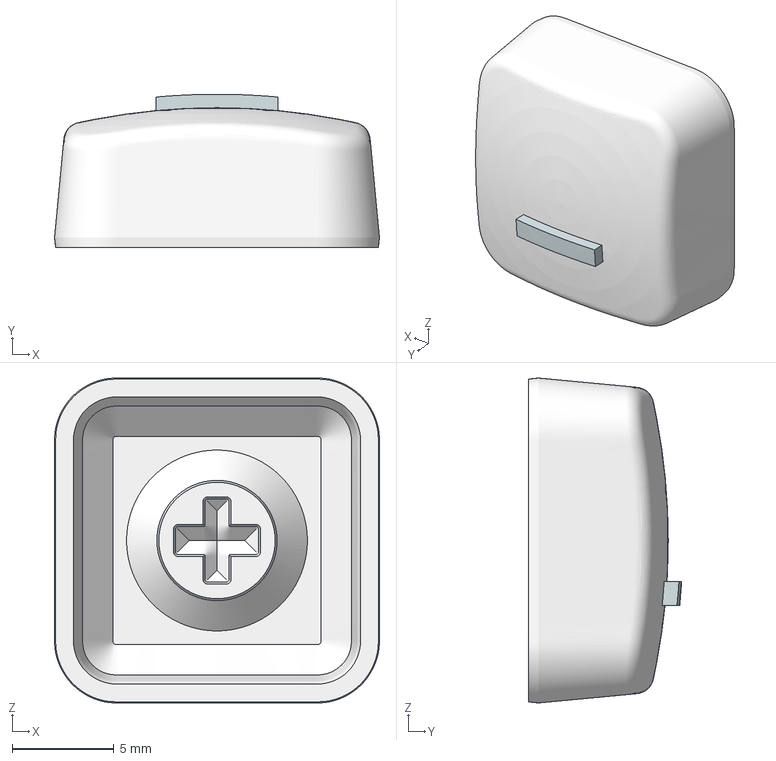
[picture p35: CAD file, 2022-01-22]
Versions/EVK_v0.1.2/3DPrinterFiles/KeyCapHome.3mf
15.9 x 7.53 x 15.9 mm

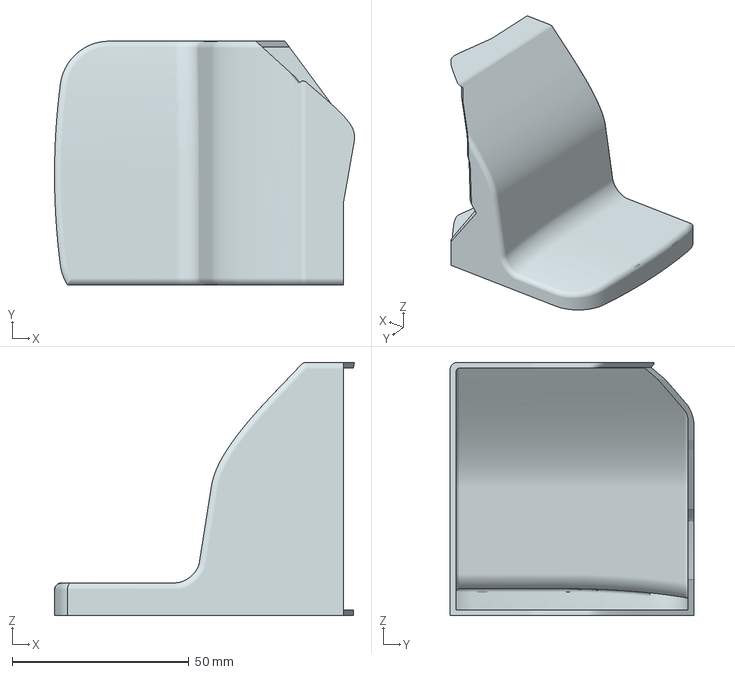
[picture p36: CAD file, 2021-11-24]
Versions/EVK_v0.1.2/3DPrinterFiles/LeftRest.3mf
85.0 x 69.0 x 71.8 mm

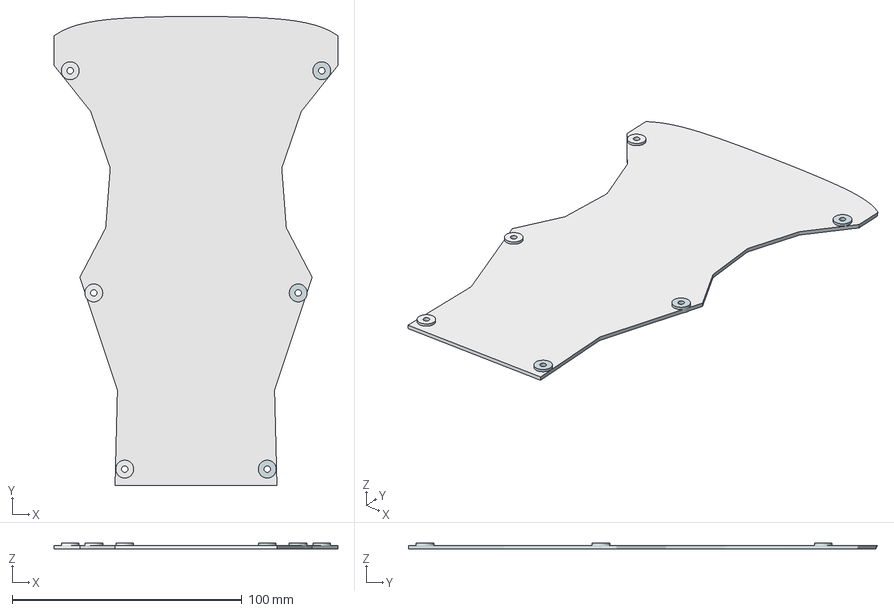
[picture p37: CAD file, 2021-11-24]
Versions/EVK_v0.1.2/3DPrinterFiles/Bottom.3mf
123.4 x 204.0 x 2.75 mm

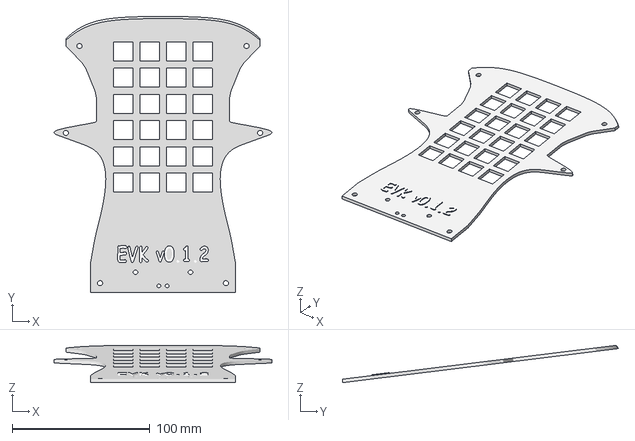
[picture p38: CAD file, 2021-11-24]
Versions/EVK_v0.1.2/3DPrinterFiles/Top.3mf
158.2 x 200.6 x 27.1 mm

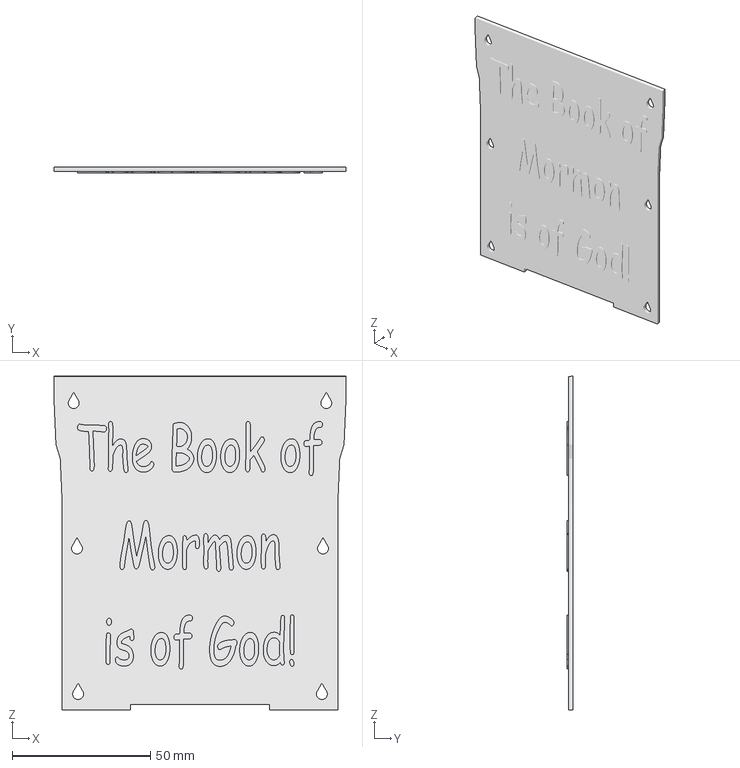
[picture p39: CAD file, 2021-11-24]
Versions/EVK_v0.1.2/3DPrinterFiles/Back.3mf
105.6 x 2.25 x 120.8 mm

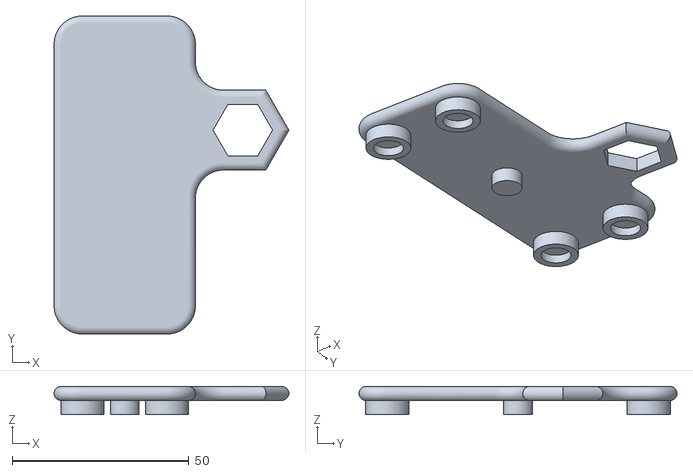
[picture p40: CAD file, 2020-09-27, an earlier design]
EVKVersions/EVK_v0.0/Case/STLFiles/HandRestLeft.stl
66.5 x 90.0 x 8.00

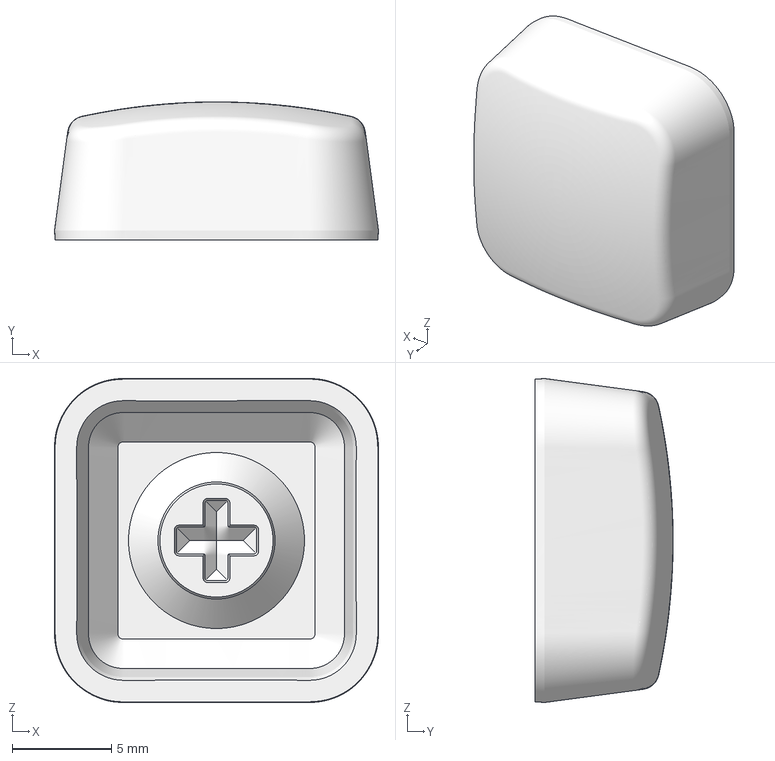
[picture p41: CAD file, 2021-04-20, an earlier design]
EVKVersions/EVK_v0.1.1/3DPrinterFiles/KeyCapNormal.3mf
16.3 x 6.97 x 16.3 mm

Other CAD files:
EVKVersions/EVK_v0.1.2/3DPrinterFiles/KeyCapNormal.3mf
EVKVersions/EVK_v0.1.2/3DPrinterFiles/KeyCapHome.3mf
Versions/EVK_v0.1.2/3DPrinterFiles/Front.3mf
Case/NX_ErgonomicVerticalKeyboard_v1.21/ConnectorFront.prt
EVKVersions/EVK_v0.0/Case/STLFiles/ConnectorBack.stl
EVKVersions/EVK_v0.0/Case/STLFiles/ConnectorFront.stl
EVKVersions/EVK_v0.1.1/3DPrinterFiles/KeyCapHome.3mf
EVKVersions/EVK_v0.1.1/3DPrinterFiles/Top.3mf
KeyboardCase/NX_ErgonomicVerticalKeyboard_v1.2/ASM_Main.prt
Versions/EVK_v0.0/Case/STLFiles/ConnectorBack.stl
Versions/EVK_v0.0/Case/STLFiles/ConnectorFront.stl
Versions/EVK_v0.0/EVK_v0.0/ASM_Electronics.prt
Versions/EVK_v0.0/EVK_v0.0/ASM_Key.prt
Versions/EVK_v0.0/EVK_v0.0/ASM_MASTER_MidFingeColumn.prt
Versions/EVK_v0.0/EVK_v0.0/ASM_SLAVE_IndexFingerColumn.prt
Versions/EVK_v0.0/EVK_v0.0/ASM_SLAVE_LittleFingerColumn.prt
Versions/EVK_v0.0/EVK_v0.0/ASM_SLAVE_MidFingerColumn.prt
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

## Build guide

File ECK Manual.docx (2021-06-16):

键盘的默认布局（可以用一只记号笔直接写在键帽上）：


按下 Toggle Layer (1) 之后的布局（这时键盘上的左LED会亮）：


也可以依照这个链接设计你自己的键盘布局。我撰写得比较简单，如有问题请问我。

https://github.com/YangPiCui/ErgonomicVerticalKeyboard/tree/master/EVKVersions/EVK_v0.1.0/ElectronicsFirmwareAndSoftware

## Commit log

2020-04-14 update to-do
    [practise.FCStd]
2020-04-14 remove practise files
    [practise.FCStd]
2020-04-15 straighten file naming convention
    [practise.FCStd]
2020-04-16 create freecad files
    [FingerPaths.FCStd]
2020-04-20 3D dimensions
    [FingerPaths.FCStd, HandAnthropometricData.xlsx, airfoil.FCStd]
2020-04-21 last update of freecad files
    [airfoil.FCStd]
2020-05-09 update Siemens NX files
    [ASM_ErgonomicVerticalKeyboard.prt, ASM_Key.prt, ASM_KeyPositions.prt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]
2020-05-12 general update
    [ASM_ErgonomicVerticalKeyboard.prt, ASM_Key.prt, ASM_KeyPositions.prt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]
2020-05-18 general design update
    [ASM_Casing.prt, ASM_ErgonomicVerticalKeyboard.prt]
2020-06-08 almost finished designing the case
    [ASM_Casing.prt, ASM_Electronics.prt, ASM_ErgonomicVerticalKeyboard.prt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]
2020-06-10 update project progress
    [ASM_Electronics.prt, ASM_ErgonomicVerticalKeyboard.prt, ASM_Key.prt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]
2020-06-10 track progress
2020-09-10 design process writeup
    [ASM_Electronics.prt, ASM_ErgonomicVerticalKeyboard.prt, ASM_ErgonomicVerticalKeyboard_v1.1.prt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]
2020-11-20 Restructure Folder for newer versions
    [ConnectorBack.stl, ConnectorFront.stl, HandAnthropometricData.xlsx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]
2020-11-21 add version 1.3
    [ASM_Electronics.prt, ASM_Key.prt, ASM_MASTER_MidFingeColumn.prt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]
2020-11-24 add teensy pin out diagram
2021-01-22 start updating v1.3
    [BackWall.stl, BottomWall.stl, FrontWall.stl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]
2021-01-22 hot glue switches
2021-02-10 add row solder picture
2021-03-19 add v1.31
    [BackWall.stl, BottomWall.stl, FrontWall.stl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]
2021-04-20 publish v1.5
    [Back.3mf, Bottom.3mf, Front.3mf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]
2021-05-03 finish v0.21
    [Back.3mf, Bottom.3mf, Front.3mf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]
2021-06-02 set 3D printer files
    [Back.3mf, Bottom.3mf, Front.3mf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]
2021-07-25 next version
    [Back.3mf, Bottom.3mf, Front.3mf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]
2021-11-24 add version v0.1.2.1
    [Back.3mf, Bottom.3mf, Front.3mf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]
2021-11-24 rename folders
    [Back.3mf, BackPlate.3mf, Bottom.3mf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]
2022-01-22 consolidate versions
    [Back.3mf, Bottom.3mf, Front.3mf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]
2022-03-18 share source file
    [ASM_Electronics.prt, ASM_Key.prt, ASM_MASTER_MidFingeColumn.prt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]
